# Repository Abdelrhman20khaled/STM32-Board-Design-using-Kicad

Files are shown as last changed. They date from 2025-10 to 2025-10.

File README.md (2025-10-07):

# STM32 Board Design using KiCad

<p align="center">
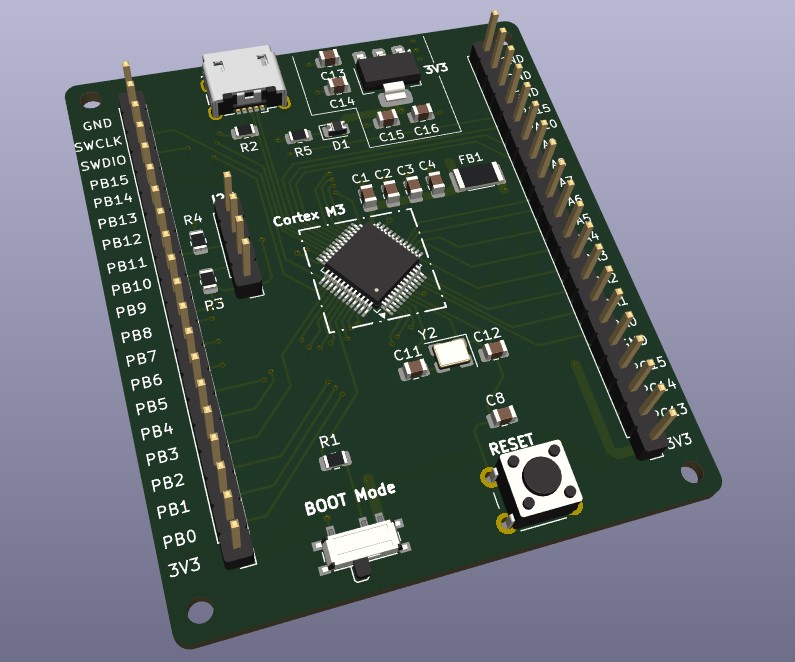
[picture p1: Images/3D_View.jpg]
3D view of board
  
</p>

<p align="center">
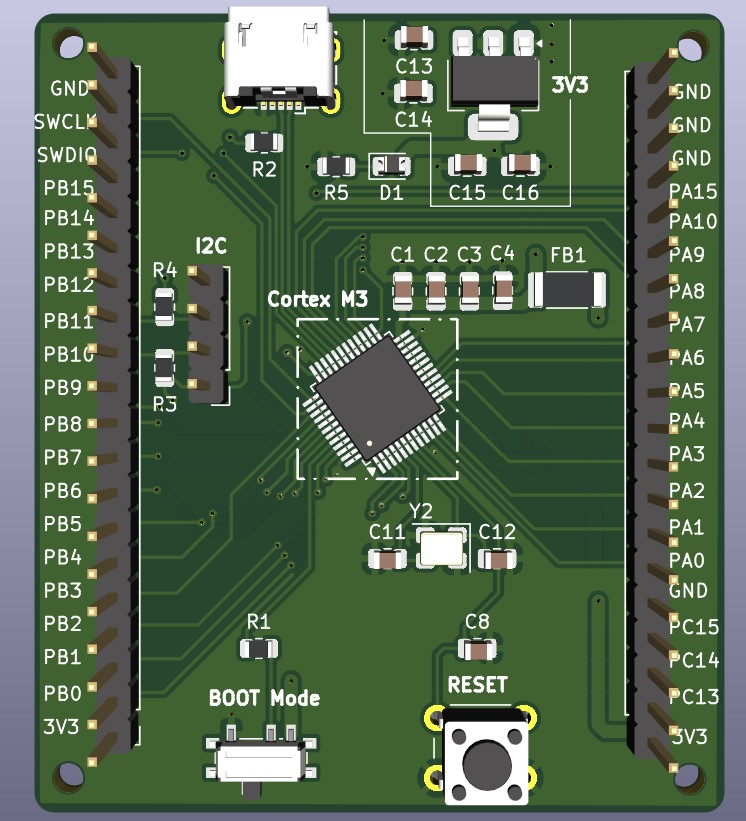
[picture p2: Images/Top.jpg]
Top view of board
  
</p>

<p align="center">
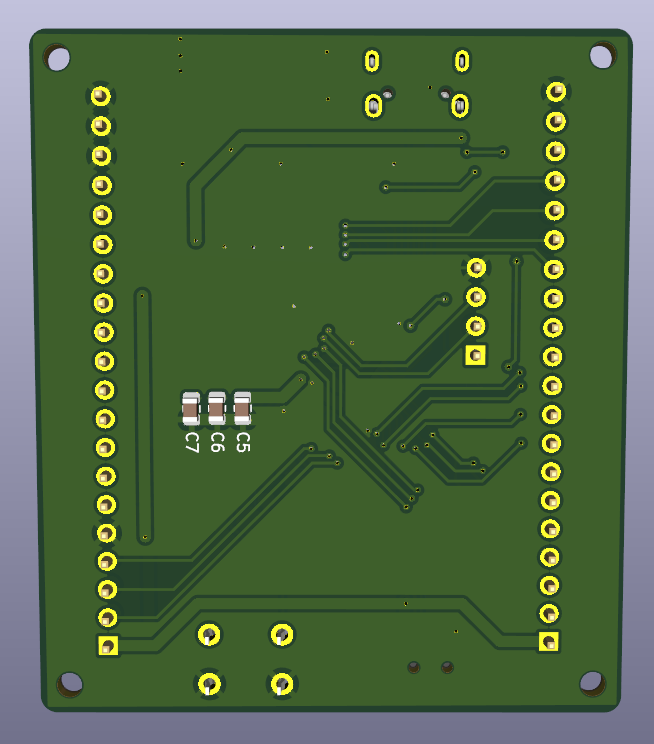
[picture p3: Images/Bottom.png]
Bottom view of board
  
</p>
<p align="center">
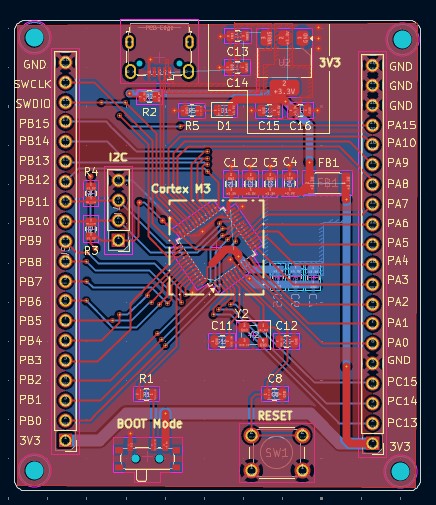
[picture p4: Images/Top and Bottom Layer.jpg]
Bottom view of board
  
</p>

## Overview

This repository showcases the design of a **custom STM32F100CTB development board**, created using **KiCad** as part of a **Learning & Development (L&D)**.
The board serves as a hands-on platform for exploring **embedded systems**, **ARM Cortex-M microcontrollers**, and **mixed-signal PCB design** practices.

The goal of this project is to provide a compact yet powerful **training and development board** that allows learners to understand the fundamentals of microcontroller hardware, PCB layout, and circuit design — from schematic to prototype.

> The image above shows the top and bottom view of the PCB — featuring the STM32 microcontroller at the center, USB Type-B port at the top, and dual GPIO headers for flexible use.

---

## Key Features

- **Microcontroller**
  - STM32F100 (ARM Cortex-M3) — ideal for entry-level embedded learning and control applications  
  - QFP package for reliable assembly and accessible signal routing  

- **Connectivity & Expansion**
  - Dual header rows (J5, J6) providing access to all GPIO pins  
  - USB Type-B connector for power and programming  
  - SWD header for debugging and firmware upload  

- **User Controls**
  - Tactile pushbutton (SW1) for reset or user input  
  - Slide switch (SW2) for mode selection or power control  

- **Power Management**
  - On-board regulation from 5V or USB to 3.3V  
  - Decoupling capacitors and ferrite filtering for clean power delivery  
  - Supports both USB and external supply input  

- **PCB Design**
  - Designed entirely in **KiCad**  
  - **4-layer stack-up** for signal and power integrity  
  - Inner layers dedicated to **power and ground planes**  
  - Careful analog/digital separation for reduced noise and EMI  
  - Compact form factor with clean routing and labeled headers  

---

## Design Goals

This board was developed with the following objectives:

- Serve as a **training and educational tool** for PCB design and embedded systems.  
- Provide a **reusable development board** for experimenting with STM32 peripherals (GPIO, UART, SPI, I²C, ADC, PWM, etc.).  
- Explore **best practices in mixed-signal layout**, decoupling, and grounding.  
- Strengthen understanding of **KiCad workflow**, from schematic capture to PCB fabrication and assembly.  

### Key Components

| Reference | Component | Function |
|---|---|---|
| U1 | STM32F100CTB | Main microcontroller |
| U2 | Voltage regulator | 5V → 3.3V conversion |
| Y2 | Crystal oscillator | MCU clock source |
| SW1 | Pushbutton | Reset/User input |
| SW2 | Slide switch | Mode/Power select |
| J5 / J6 | Pin headers | GPIO expansion |
| J4 | SWD header | Debug/programming interface |
| USB | Type-B connector | Power & communication |

---

## Learning Outcomes

Through this project, students and engineers gain hands-on experience with:

- **Schematic design** in KiCad  
- **Component library management**   
- **Grounding and decoupling strategies**  

This board also provides a reusable reference for future mixed-signal designs and embedded control experiments.

---

## Applications

- Embedded systems education and prototyping  
- Real-time control and automation projects  
- Peripheral testing and firmware development  
- Hardware design learning modules  

---

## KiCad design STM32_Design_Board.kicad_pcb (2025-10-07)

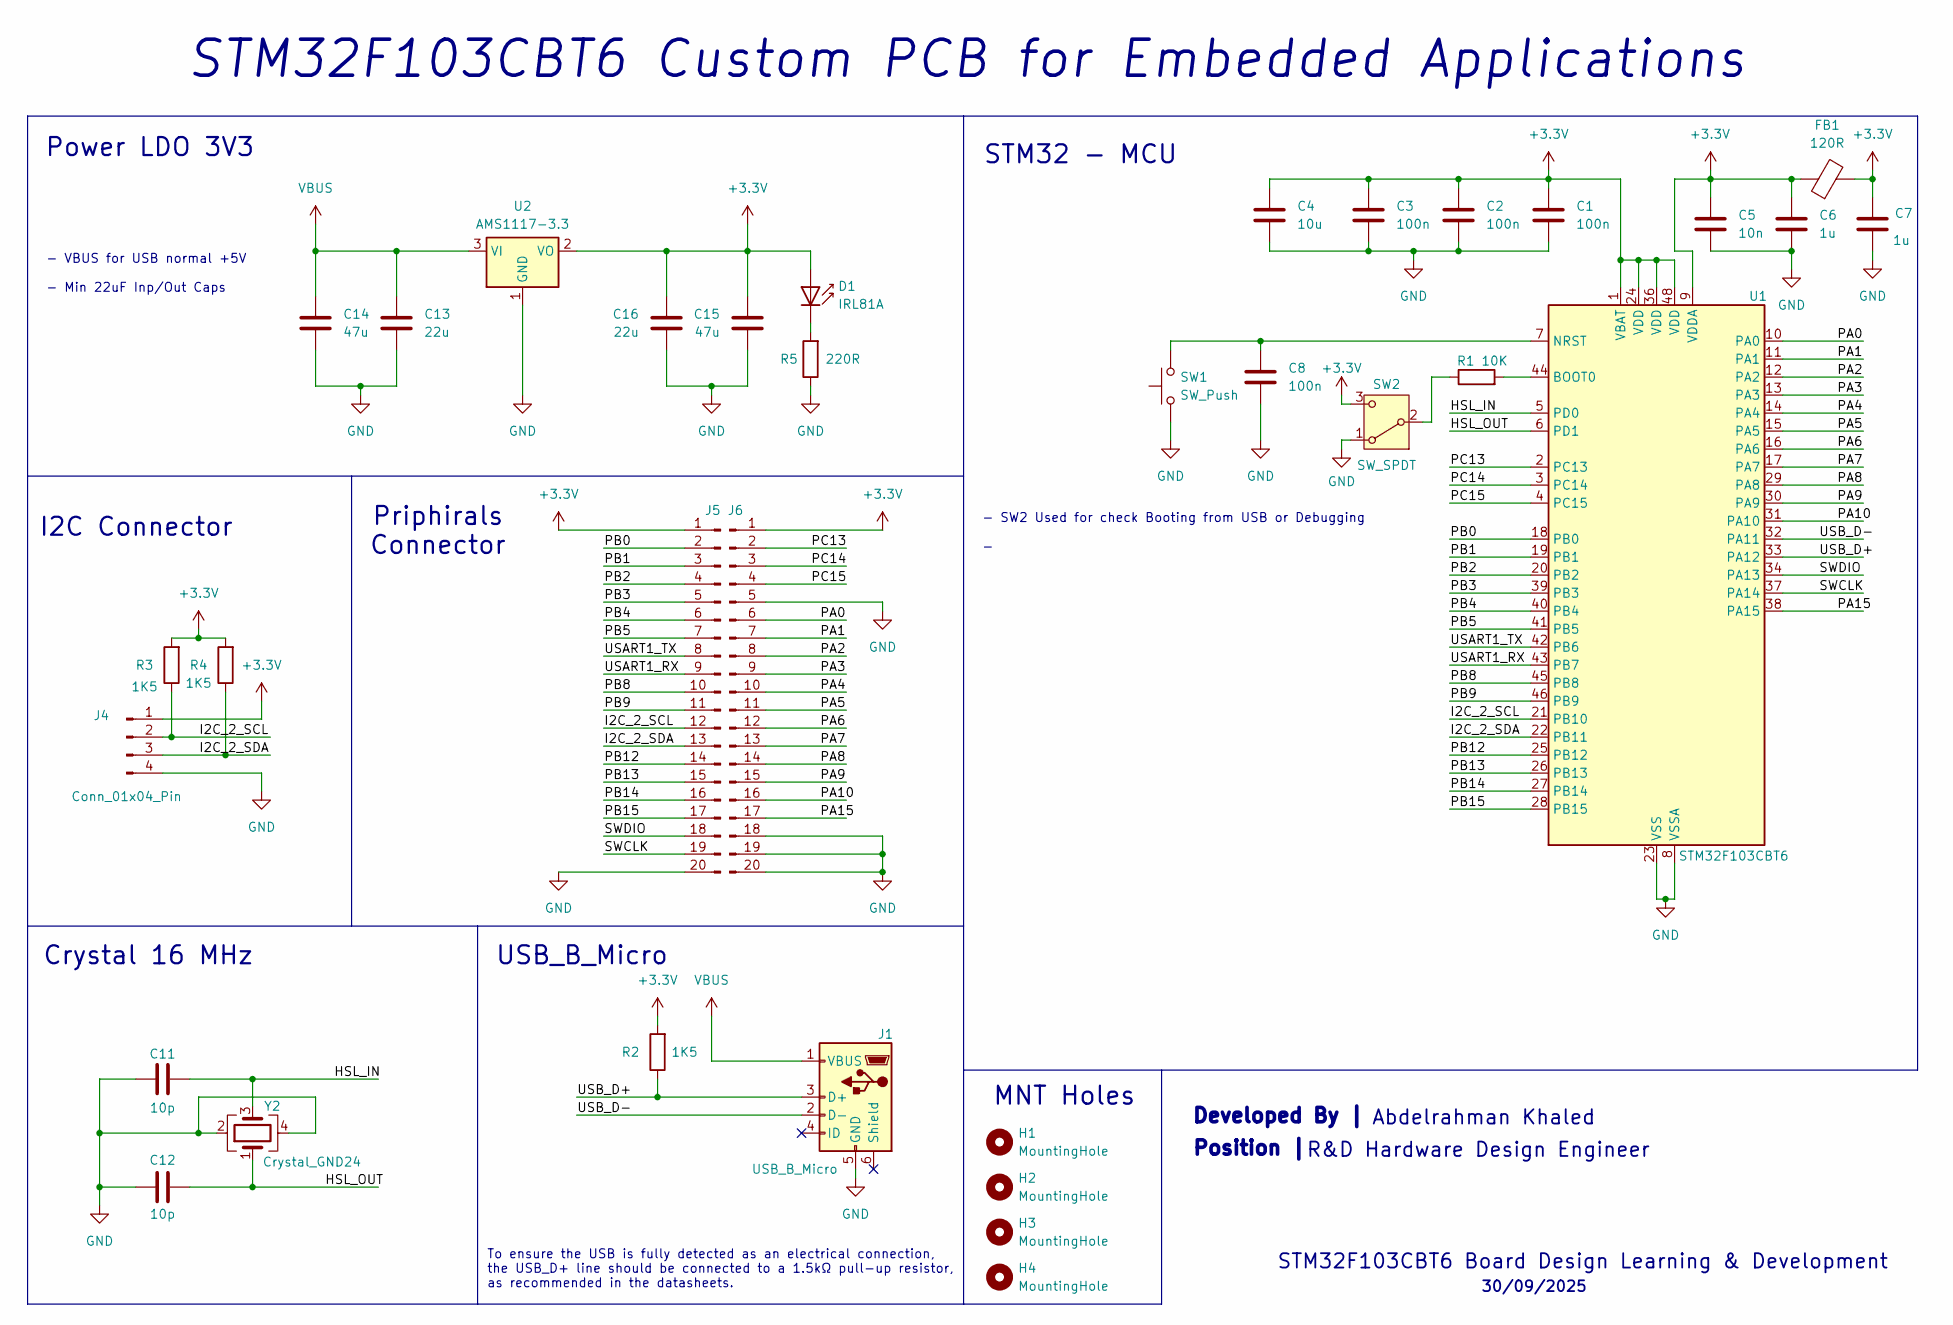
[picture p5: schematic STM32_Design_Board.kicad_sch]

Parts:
C1, C2, C3, C8: 100n; C_0805_2012Metric
C4: 10u; C_0805_2012Metric
C5: 10n; C_0805_2012Metric
C6, C7: 1u; C_0805_2012Metric
C11, C12: 10p; C_0805_2012Metric
C13, C16: 22u; C_0805_2012Metric
C14, C15: 47u; C_0805_2012Metric
D1: IRL81A; D_0805_2012Metric
FB1: 120R; R_2010_5025Metric
H1, H2, H3, H4: MountingHole; MountingHole_2.2mm_M2_ISO14580
J1: USB_B_Micro; USB_Micro-B_Wuerth_629105150521
J4: Conn_01x04_Pin; PinHeader_1x04_P2.54mm_Vertical
J5, J6: Conn_01x20_Pin; PinHeader_1x20_P2.54mm_Vertical
R1: 10K; R_0805_2012Metric
R2, R3, R4: 1K5; R_0805_2012Metric
R5: 220R; R_0805_2012Metric
SW1: SW_Push; SW_PUSH_6mm_H4.3mm
SW2: SW_SPDT; SW_SPDT_PCM12
U1: STM32F103CBT6; LQFP-48_7x7mm_P0.5mm
U2: AMS1117-3.3; SOT-223-3_TabPin2
Y2: Crystal_GND24; Crystal_SMD_SeikoEpson_FA238V-4Pin_3.2x2.5mm

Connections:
+3.3V: C1.1, C2.1, C3.1, C4.1, C5.1, C6.1, C7.1, C15.1, C16.1, D1.2 (A), FB1.1, FB1.2, J4.1, J5.1, J6.1, R2.2, R3.2, R4.2, SW2.3 (C), U1.1 (VBAT), U1.9 (VDDA), U1.24 (VDD), U1.36 (VDD), U1.48 (VDD), U2.2 (VO)
/HSL_IN: C11.2, U1.5 (PD0), Y2.3
/HSL_OUT: C12.2, U1.6 (PD1), Y2.1
/I2C_2_SCL: J4.2, J5.12, R3.1, U1.21 (PB10)
/I2C_2_SDA: J4.3, J5.13, R4.1, U1.22 (PB11)
/PA0: J6.6, U1.10 (PA0)
/PA1: J6.7, U1.11 (PA1)
/PA2: J6.8, U1.12 (PA2)
/PA3: J6.9, U1.13 (PA3)
/PA4: J6.10, U1.14 (PA4)
/PA5: J6.11, U1.15 (PA5)
/PA6: J6.12, U1.16 (PA6)
/PA7: J6.13, U1.17 (PA7)
/PA8: J6.14, U1.29 (PA8)
/PA9: J6.15, U1.30 (PA9)
/PA10: J6.16, U1.31 (PA10)
/PA15: J6.17, U1.38 (PA15)
/PB0: J5.2, U1.18 (PB0)
/PB1: J5.3, U1.19 (PB1)
/PB2: J5.4, U1.20 (PB2)
/PB3: J5.5, U1.39 (PB3)
/PB4: J5.6, U1.40 (PB4)
/PB5: J5.7, U1.41 (PB5)
/PB8: J5.10, U1.45 (PB8)
/PB9: J5.11, U1.46 (PB9)
/PB12: J5.14, U1.25 (PB12)
/PB13: J5.15, U1.26 (PB13)
/PB14: J5.16, U1.27 (PB14)
/PB15: J5.17, U1.28 (PB15)
/PC13: J6.2, U1.2 (PC13)
/PC14: J6.3, U1.3 (PC14)
/PC15: J6.4, U1.4 (PC15)
/SWCLK: J5.19, U1.37 (PA14)
/SWDIO: J5.18, U1.34 (PA13)
/USART1_RX: J5.9, U1.43 (PB7)
/USART1_TX: J5.8, U1.42 (PB6)
/USB_D+: J1.3 (D+), R2.1, U1.33 (PA12)
/USB_D-: J1.2 (D-), U1.32 (PA11)
GND: C1.2, C2.2, C3.2, C4.2, C5.2, C6.2, C7.2, C8.2, C11.1, C12.1, C13.2, C14.2, C15.2, C16.2, J1.5 (GND), J4.4, J5.20, J6.5, J6.18, J6.19, J6.20, R5.1, SW1.1, SW2.1 (A), U1.8 (VSSA), U1.23 (VSS), U1.35 (VSS), U1.47 (VSS), U2.1 (GND), Y2.2, Y2.4
unnamed: D1.1 (K), R5.2
unnamed: R1.1, SW2.2 (B)
unnamed: R1.2, U1.44 (BOOT0)
unnamed: C8.1, SW1.2, U1.7 (NRST)
VBUS: C13.1, C14.1, J1.1 (VBUS), U2.3 (VI)

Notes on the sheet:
USB_B_Micro
- SW2 Used for check Booting from USB or Debugging -
Abdelrahman Khaled
To ensure the USB is fully detected as an electrical connection, the USB_D+ line should be connected to a 1.5kΩ pull-up resistor, as recommended in the datasheets.
STM32F103CBT6 Board Design Learning & Development
MNT Holes
STM32 - MCU
STM32F103CBT6 Custom PCB for Embedded Applications
I2C Connector
- VBUS for USB normal +5V - Min 22uF Inp/Out Caps
Priphirals Connector
Crystal 16 MHz
R&D Hardware Design Engineer
Developed By |
Position |
Power LDO 3V3
30/09/2025

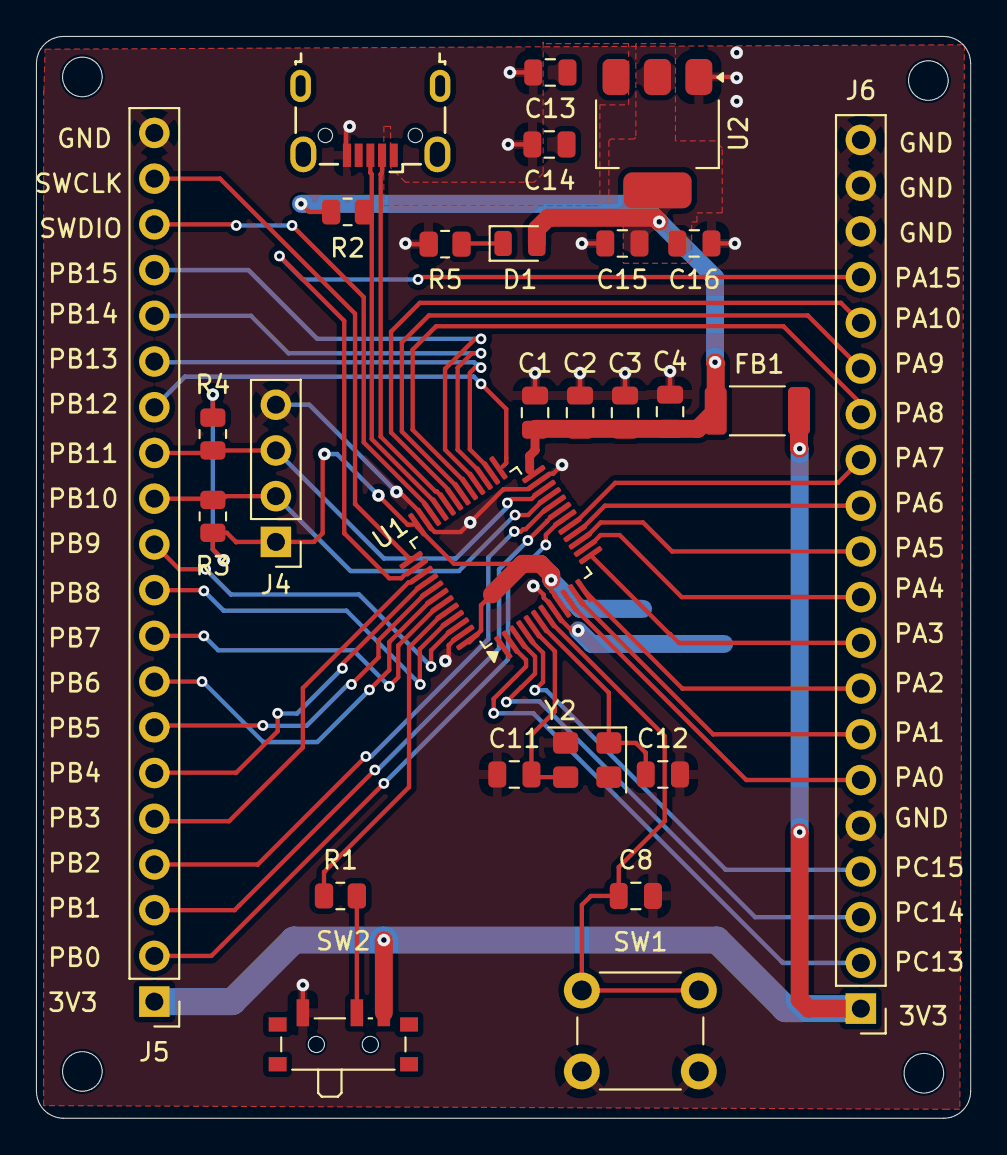
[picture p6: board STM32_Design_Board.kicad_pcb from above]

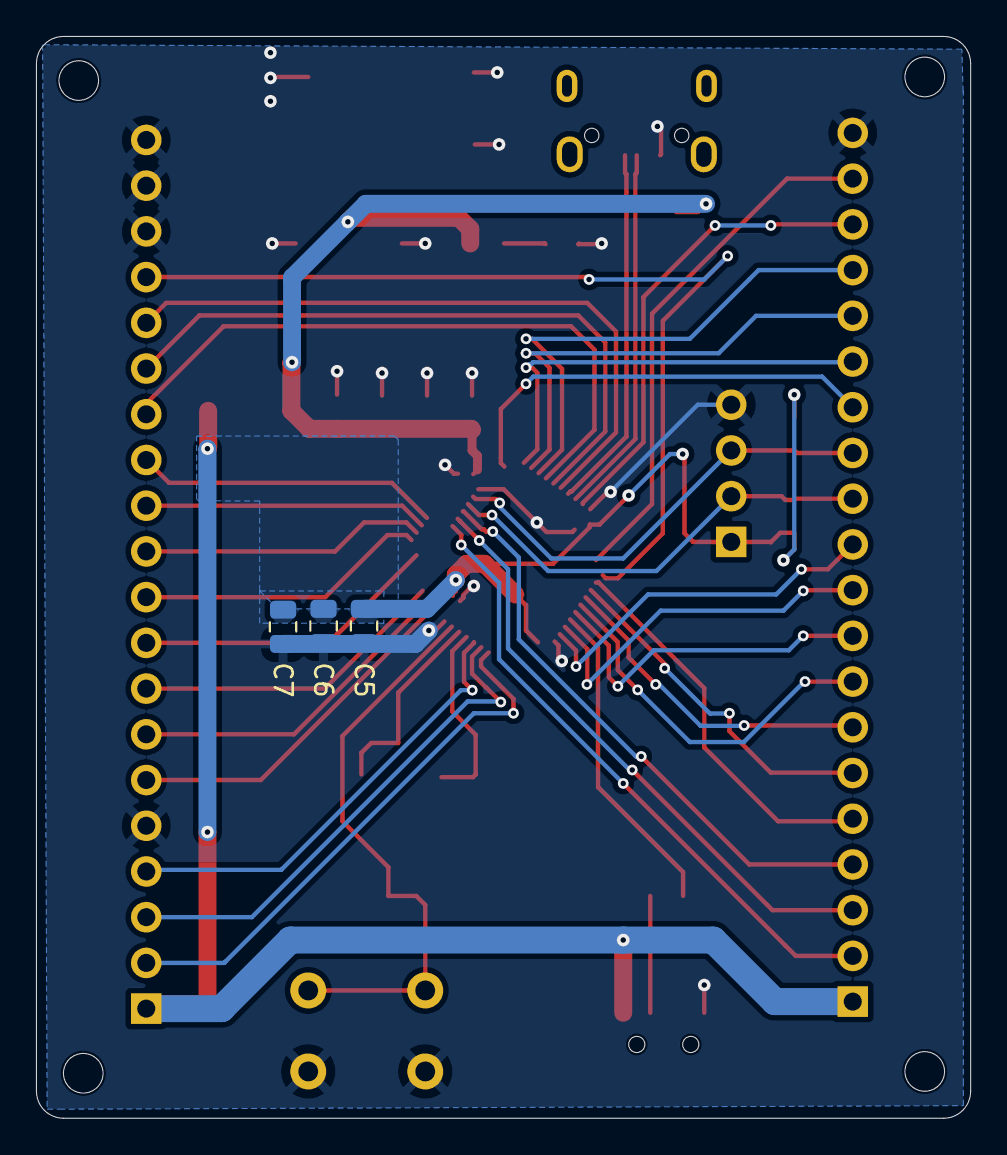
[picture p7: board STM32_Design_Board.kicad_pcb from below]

Board: 2 copper layers, 51.9 x 60.1 mm, 34 parts (3 on the bottom side), 44 nets.
